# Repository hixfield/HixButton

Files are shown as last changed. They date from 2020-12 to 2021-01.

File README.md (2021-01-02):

# HixButton

![Build with PlatformIO](https://img.shields.io/badge/build%20with-PlatformIO-orange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)

A simple fully designed ESP8266 WIFI button.
With schematic, PCB layout and the 3D printed case.

[See it on thingiverse](https://www.thingiverse.com/thing:4697256)

[See it on youtube](https://youtu.be/lKFYbrJro3M)

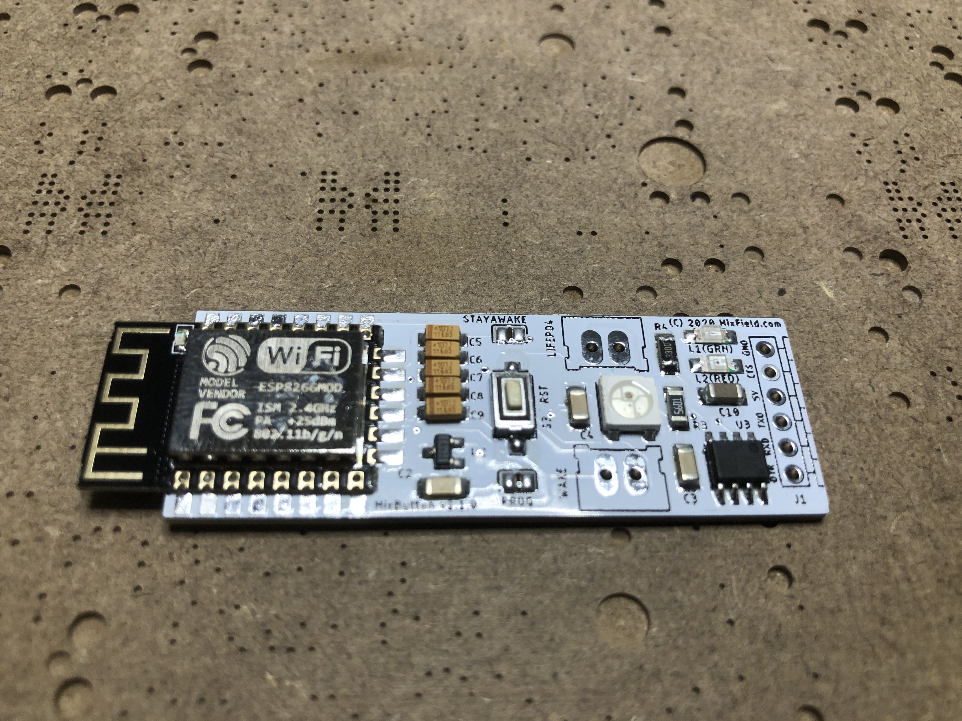
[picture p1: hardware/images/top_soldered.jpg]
PCB top view
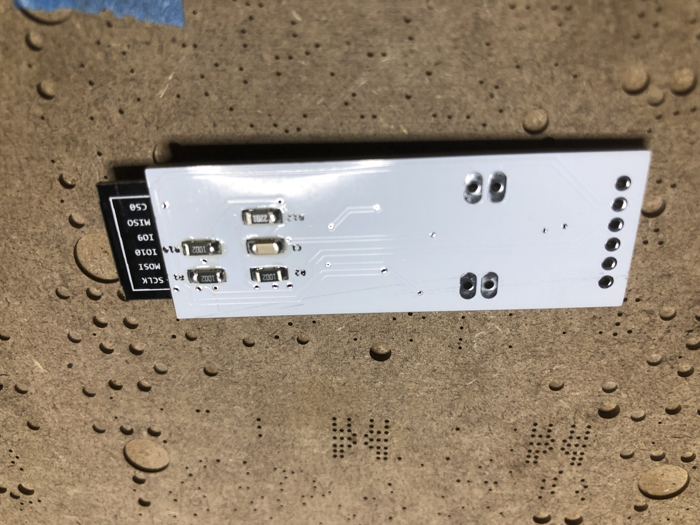
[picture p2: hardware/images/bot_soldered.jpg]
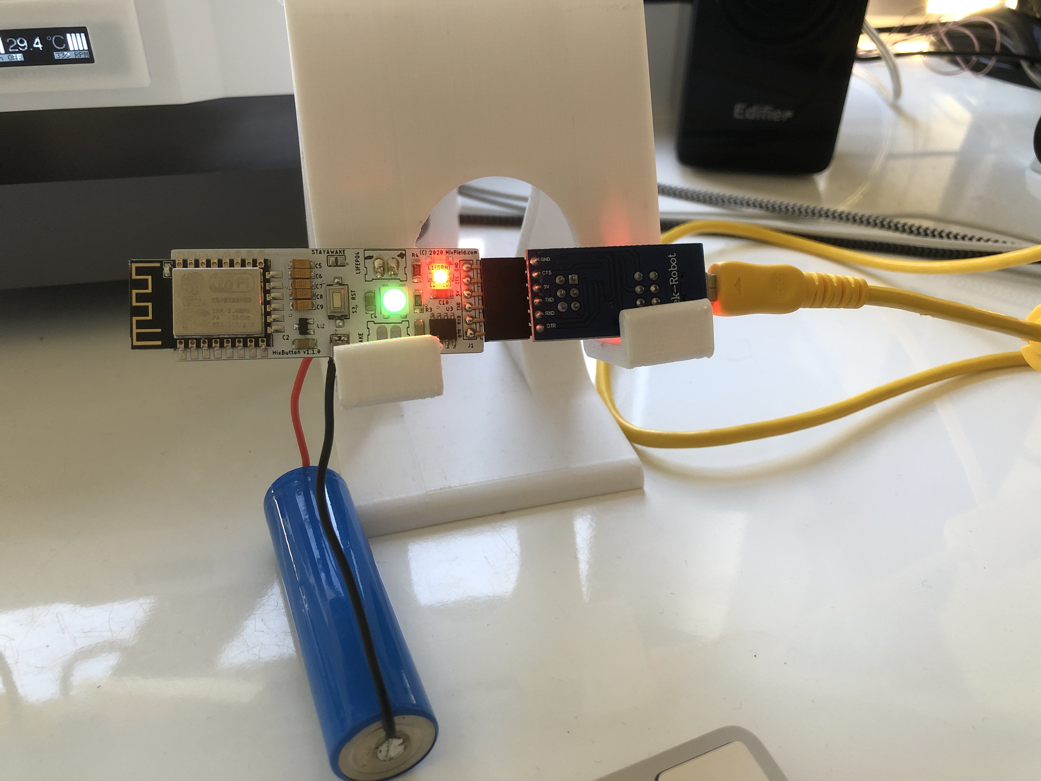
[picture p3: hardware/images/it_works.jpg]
|  |  |  |
|---|---|---|
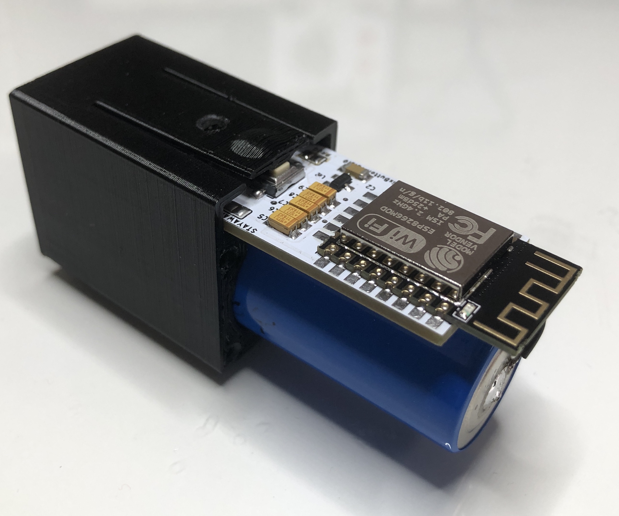
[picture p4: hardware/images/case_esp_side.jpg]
Case ESP side
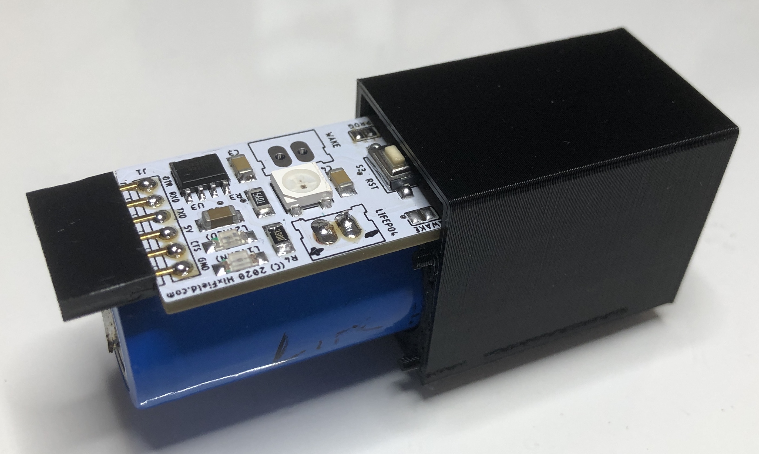
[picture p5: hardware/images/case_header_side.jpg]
Case header side
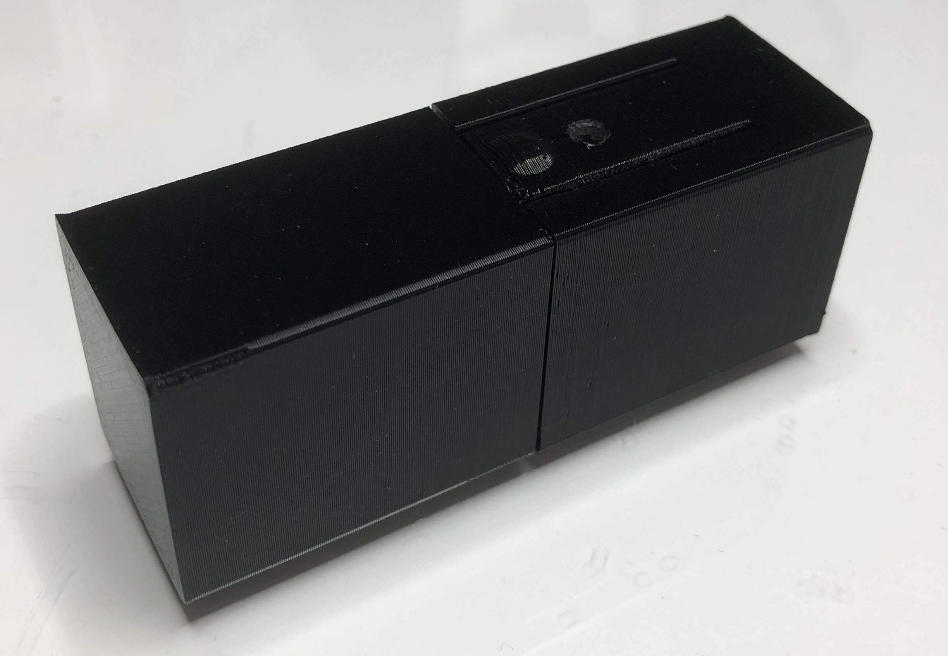
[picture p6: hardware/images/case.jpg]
Case
|  |  |  |
|Case ESP side|Case header side|Fuly assembled|

## Features

- Powered by a single LiFePo4 battery (one charge lasts > 1 year)
- Onboarding charging circuit based on CN3058E powered via the FTDI connector's 5V
- Onboard power supervisor to make sure ESP does not boot (with garbage) if batery is to low
- Contains an RGB led (used to signal status back from the server e.g. heating on or off, and locally also used to signal low battery condition)
- Firmware sends a json formatted datagram (UDP)
 * to any configurable server
 * and optionally receives datagram back (UDP) to set status led (and its duration)
 * sends over battery status so server can signal low bat conditions
- Works great with Node-red e.g. running on Raspberry Pi
- Solder jumper to keep module awake (during debugging)
- Puts the ESP in a deep sleep after pressing the button to conserve battery power.
- Fast WiFi connection establish techniques (e.g. fixed ip) to make button responsive
- 3D printed finished case

## Improvements

- [x] external NO connector to have external input (over RST switch) -> use it to make e.g. "I have mail in my mailbox"
- [x] External FTDI programming connector 
- [x] LiFePO4 under voltage protection
- [x] Replace the big elco cap to multiple tantilums to not be so high
- [x] connect ftdi to 5v (its not 3.3) and use this as charging connector
- [x] rgb led part no uxxx and type
- [x] charging chip no uxxx and type
- [x] adjust charging resistor
- [x] use power and signal nets in sch and then test if these are used for pcb routing
- [x] lets order a stencel for the PCB to test it :)
- [x] add LiFePO4 bat charging circutry (add external connector)
- [x] FTDI power is always 5V use this for battery charing (but limit current)
- [ ] OTA programming?

## Will not do
- [x] Put CH340 USB serial on it (to complex for once programming)
- [x] don't go to sleep if (1)FTDI plugged-in (2)charing power applied
- [x] change push switch type, the one we have should do the trick

# Hardware

[Click here for hardware information](hardware/README.md)

# Software

[Click here for software information](software/README.md)

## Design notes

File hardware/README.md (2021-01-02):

# Get an impression :-)
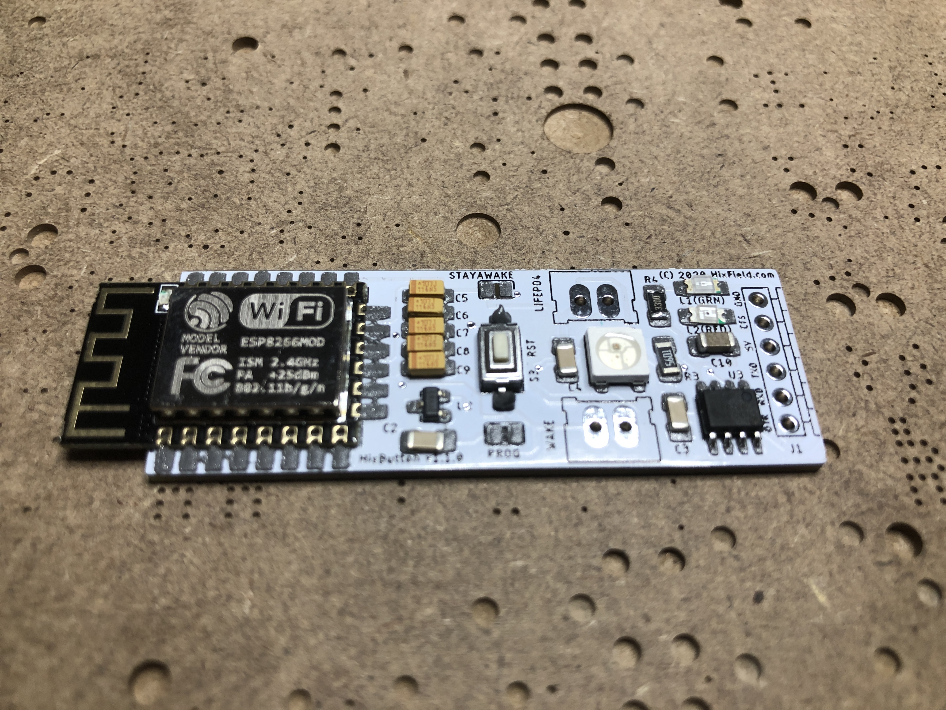
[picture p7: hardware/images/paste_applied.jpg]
|  | PCB bottom view | PCB bottom view |
|---|---|---|
|solder paste applied|after headgun: soldered!|and bottom too|
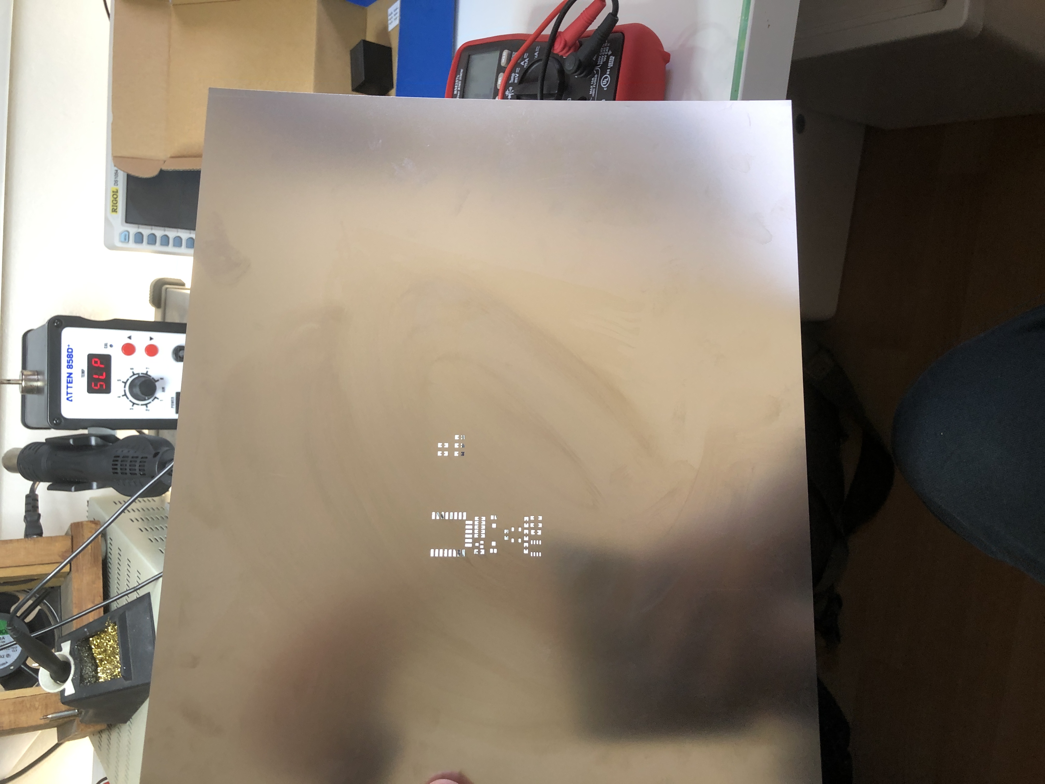
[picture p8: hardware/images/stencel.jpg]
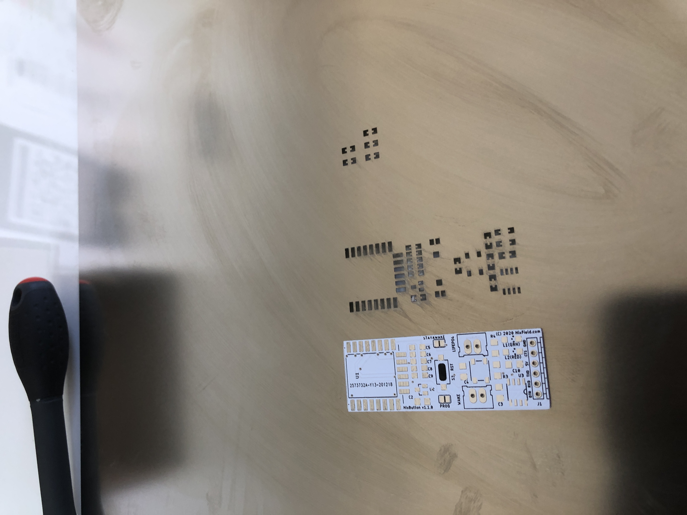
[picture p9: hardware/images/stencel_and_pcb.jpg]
| PCB bottom view |  |  |
|it works!|also ordered solder stencel|stencel and pcb|
| Case ESP side | Case header side | Case |
|Case ESP side|Case header side|Fuly assembled|
# 3D printed case
You can find all requird `stl`files on [thingiverse](https://www.thingiverse.com/thing:4697256) (and in the `case` folder of this repo)

Case asembly (https://youtu.be/lKFYbrJro3M)

# Schematic

- LiFePO4 charging current set as `I = 1.205/R3` (schematic lists 5.6K which is approx 200mA to keep things cool)
 
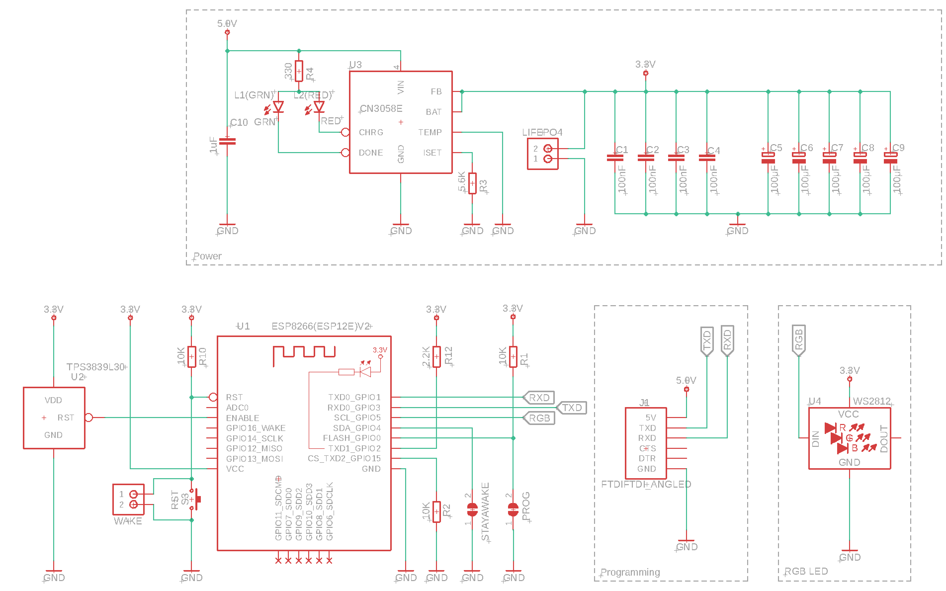
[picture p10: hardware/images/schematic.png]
Schematic


# PCB
| Top | Bottom |
|---|---|
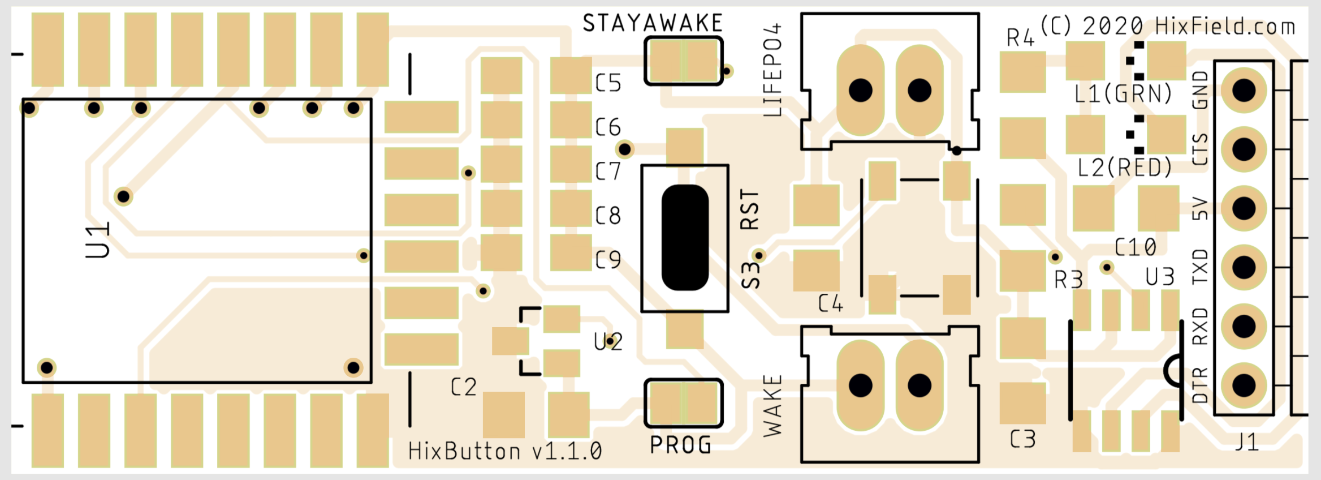
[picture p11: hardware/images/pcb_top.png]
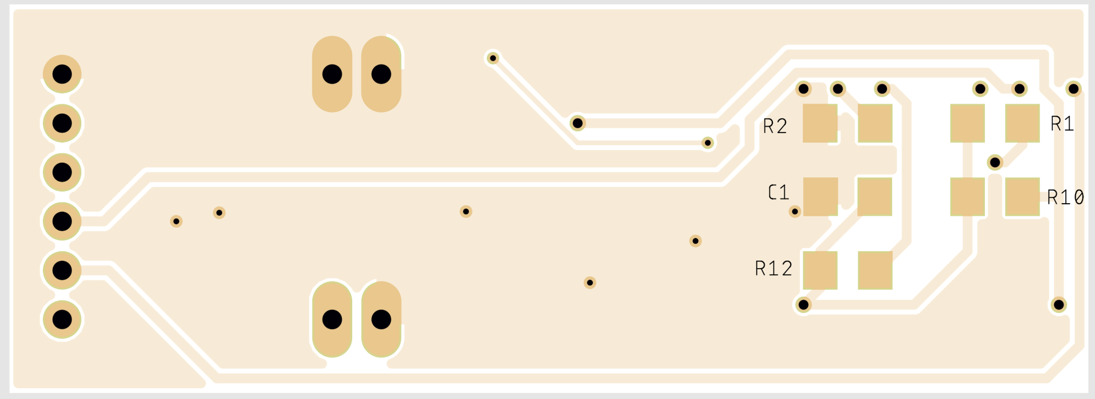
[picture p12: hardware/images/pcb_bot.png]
|  |  |

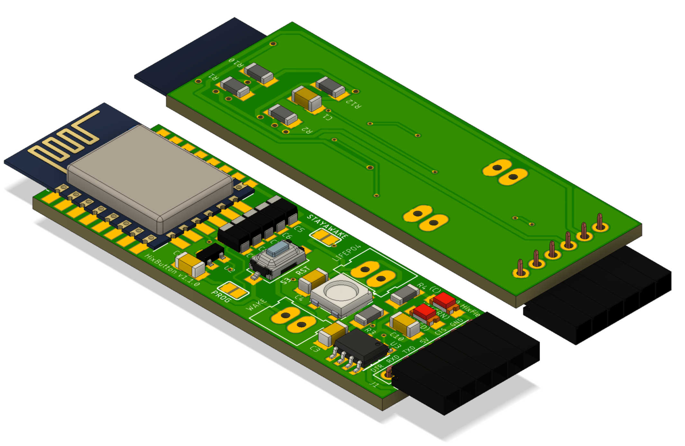
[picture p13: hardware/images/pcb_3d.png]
3D PCB


# BOM
|Qty|Value |Device |Parts |
|---|---|---|---|
|4  |100nF |SMD 1206 |C1, C2, C3, C4 |
|5  |100μF |Tantalum SMD 1206 |C5, C6, C7, C8, C9|
|3  |10K |SMD 1206 |R1, R2, R10 |
|1  |1uF |SMD 1206 |C10 |
|1  |2.2K |SMD 1206 |R12 |
|1  |330 |SMD 1206 |R4 |
|1  |5.6K |SMD 1206 |R3 |
|1  |CN3058E |CN3058E |U3 |
|1  |ESP12E |ESP12E |U1 |
|1  |FTDI |6P Female header |J1 |
|1  |GRN |LED 1206 Green |L1(GRN) |
|1  |RED |LED 1206 Red |L2(RED) |
|1  |RST |PUSHBTNSMALL |S3 |
|1  |TPS3839L30|TPS3839L30 |U2 |
|1  |WS2812 |LED RGB WS2812 SMD 5050|U4 |

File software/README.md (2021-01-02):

# HixCO2TemperatureIRBlaster - Firmware

![Build with PlatformIO](https://img.shields.io/badge/build%20with-PlatformIO-orange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)


## What does the firmware do?
* when the button is pressed the device is reset
* the different hardware components are configured quickly (serial baut rate, RGB led...)
* the configuration is loaded (from EEPROM). This contains the WIFI settings.
* the voltage of the battery is measured and if to low the RGB led flashed red rapidly to sigbal low bat
* the device now tries to connect to the WIFI
* if the WIFI connection does not work, the RGB led turns white / fading in-out and the device is put in AP mode (see WIFI setup & configuration)
* if WIFI is connected a UDP datagram is send to the configuration server (refer to Datagram contents) containing lots of details also status battery
* the device then waits for 2 seconds for receiving a datagram, if received its decoded to see if it contains a led color and duration. This is then use to set the RGB. -> very neat way to sigal simple status back from the server to the user!
* if the device solder jumper "STAY AWAKE" is not closed, the device is put into deepsleep. This should be used for debuggin only (drains battery)!

## How to flash the device

### Step 0: software confirmation
* make sure you have PlatformIO correctly setup in your Microsoft Visual Studio Code
* open the software folder in Microsoft Visual Studio Code
* configure your default settings in the secret.cpp file

### Step 1: initial upload via serial cable
* make sure your USB/FTDI is set to **3.3V**
* insert your USB to FTDI on the PCB
* there is a solder jumper "prog", using a screwdriver close it and then press the button (= reset button) while still keeping the solder jumper closed.
* you can now let go of the screwdriver, the device should now be in programming mode
* open the platformio.ini and configure the upload port and speed to use your USB/FTDI for example:
	- `upload_speed = 460800`
	- `upload_port = /dev/cu.usbserial-A50285BI`
* upload to the device
* press the button and the device should boot, but it will take much longer then usual because the SPIFFS is not yet flashed

### Step 2: upload the SPIFFS filesystem
* the SPIFFS filesystem is used to store files required for the configuration web interface (only activated if the device cannot connect to the WIFI)
* put the device in programming mode again (refer to procedure above)
* in platformIO select "Upload Filesystem image"
* press the button, the device will reboot

### Step3 : see boot information
* connect using 115200 baut
* if you open the serial monitor the device outputs a lot of info

## WIFI setup and configuration
### force stay awake
* if you want to configure the device, and prevent it from going to sleep when pressing the button, close the solder jumper `STAYAWAKE` then the configuration interface will always be active. The RGB LED will turn magenta to indicate the jumper is closed. **You have to remove this solder jumper after config because this will drain the battery very quickly!**. 
* the device has mDNS enabled and will listen for `{room}_hixbutton_{tag}` where `{room}` and `{tag}` are defined in configuration (with defaults configured in `secret.cpp`)

### automatic access point creation
* when you press the button and the device cannot connect using its stored WIFI settings the RGB led will turn white and it will enable an access point (AP)
* after 10 minutes and if nobody is connected to the AP, the device goes to sleep again
* using a computer, tablet, phone... connect to the access point and enter the IP address of the device (192.168.4.1)
* you will now see the web configuration screen that you can use the configure all settings:
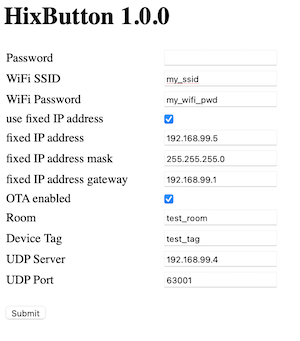
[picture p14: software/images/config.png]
config web interface


## Send UDP datagram contents
Datagram is one json document containing the following information:

```
 {
   "device_type":"HixButton",
   "device_version":"1.0.0",
   "device_tag":"test_tag",
   "room":"test_room",
   "wifi_ssid":"GEMIC_2.4Ghz",
   "wifi_rssi":-78,
   "wifi_mac": "E0:98:06:84:9B:F6",
   "vcc":3.42208
}
```
* `device_tag` and `room` are configured (via secret.cpp for defaults or via the config inferface) and identify the device. If you have mulitple devices this is what you use to differentiate between tem
* `wifi_rssi` gives an idea of the WIFI signal strenght
* `vcc` is the voltage level of the battery. You can use this to raise an alarm (if < 2.65v typically) on the server side

## Recieve UDP datagram contents
- You must send a reply within 2 seconds to the device (otherwise its already in sleep and will not respond anymore)
- You can see the color and duration for the RGB led:

```
{
   "ledColorRGBHex":"FF0000",
   "sleepDelayMs":3000
}
```
# Usage with Node-RED
I created 2 subflow components

- HixButton press -> input for detecting button presses
- HixButton status -> after press use this to post back RGB led color and duration to device

Here is my main flow:

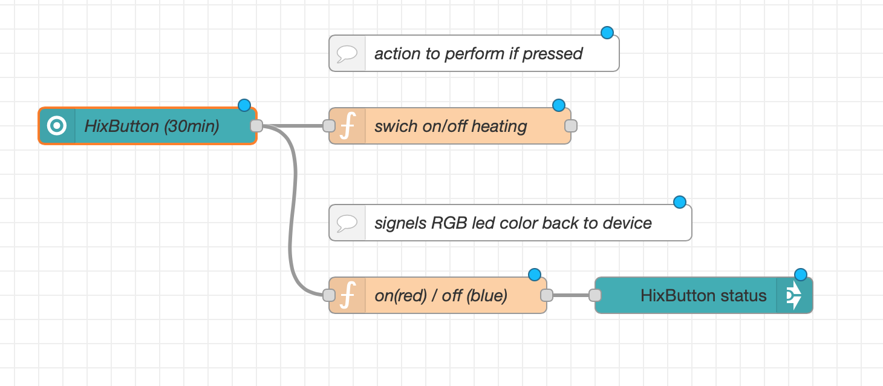
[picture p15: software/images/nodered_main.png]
main flow


With configuration of both subflow properties (flow json underneath pictures):

| Press | Status |
|---|---|
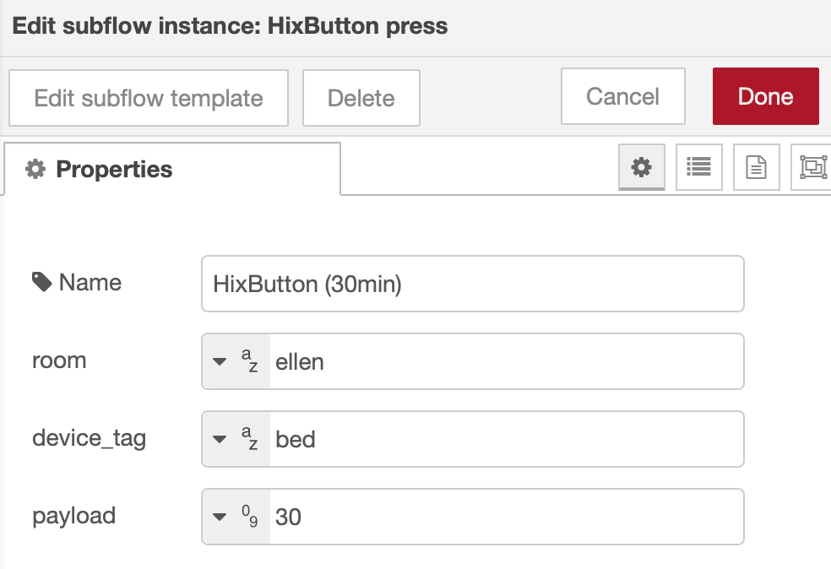
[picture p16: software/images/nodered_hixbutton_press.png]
hixbutton press properties
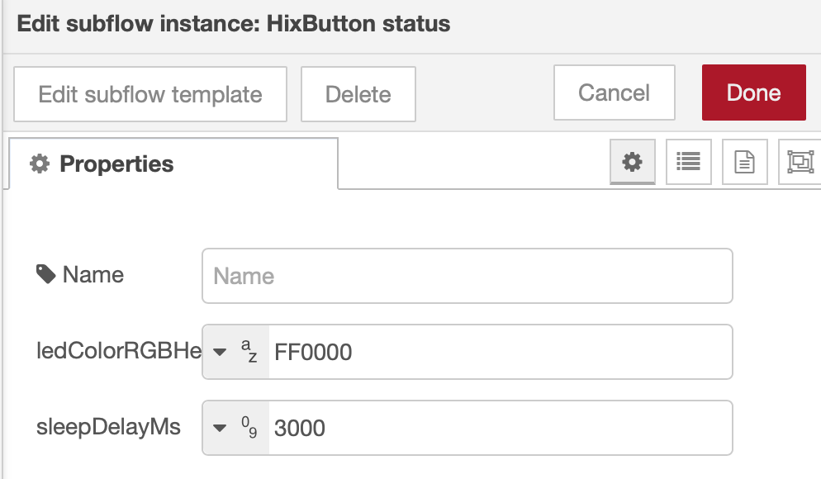
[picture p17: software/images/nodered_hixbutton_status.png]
hixbutton status properties
|  |  |
| [hixbutton press flow json (cut and past in node-RED)](images/nodered_hixbutton_press.json) | [hixbutton status flow json (cut and past in node-RED)](images/nodered_hixbutton_status.json) |

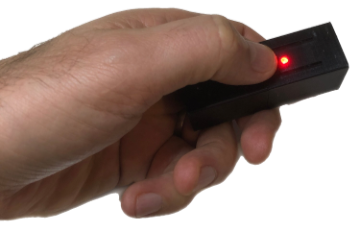
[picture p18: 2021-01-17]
hardware/images/hand_pressing_button.png

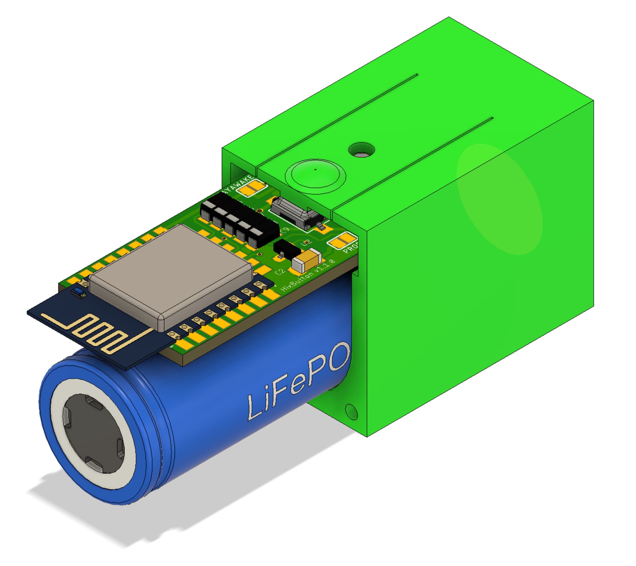
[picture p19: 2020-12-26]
hardware/images/case_3d_header_side.jpg

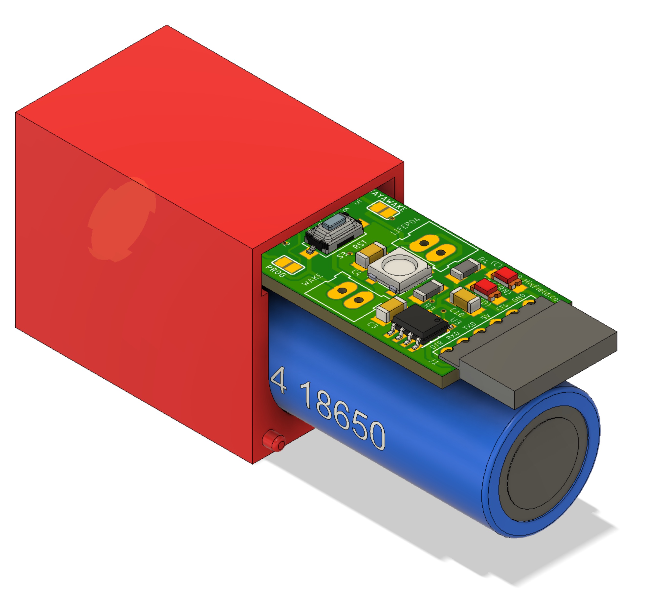
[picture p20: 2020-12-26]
hardware/images/case_3d_esp_side.jpg

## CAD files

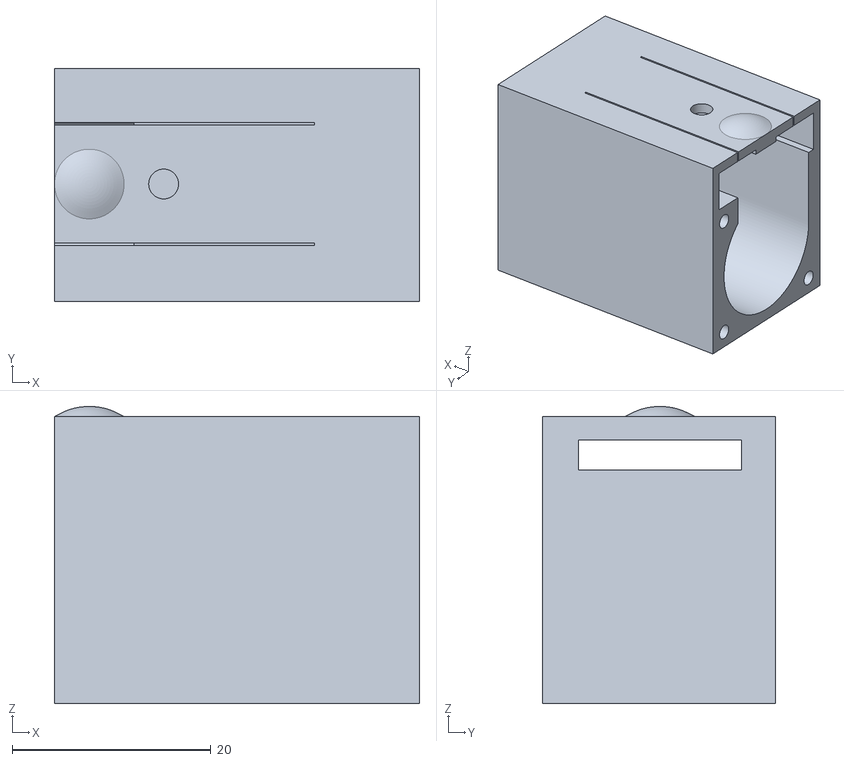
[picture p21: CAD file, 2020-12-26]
hardware/case/half_header_side.stl
36.7 x 23.4 x 29.9

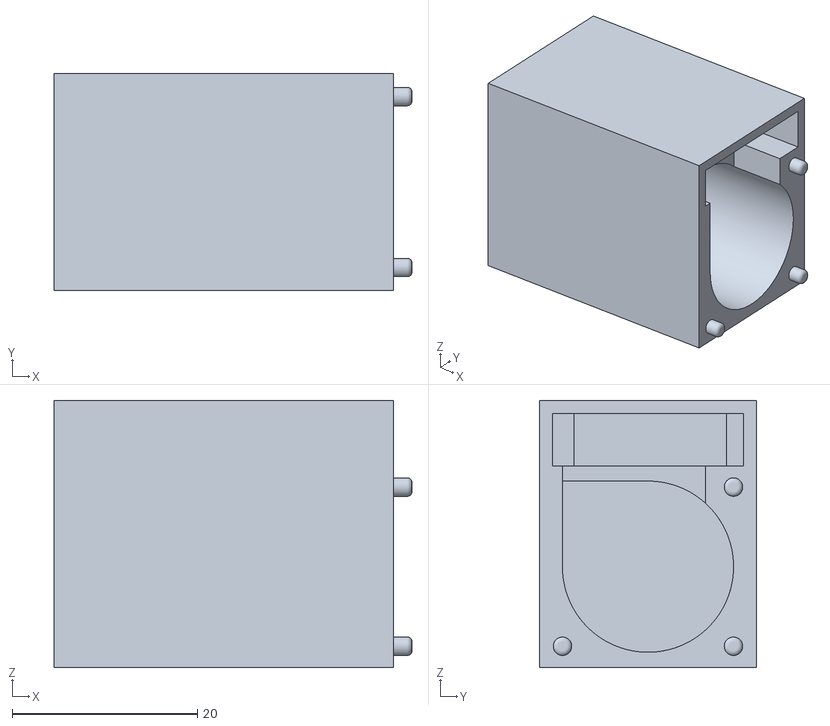
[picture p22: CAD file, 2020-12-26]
hardware/case/half_esp_side.stl
38.7 x 23.4 x 28.9

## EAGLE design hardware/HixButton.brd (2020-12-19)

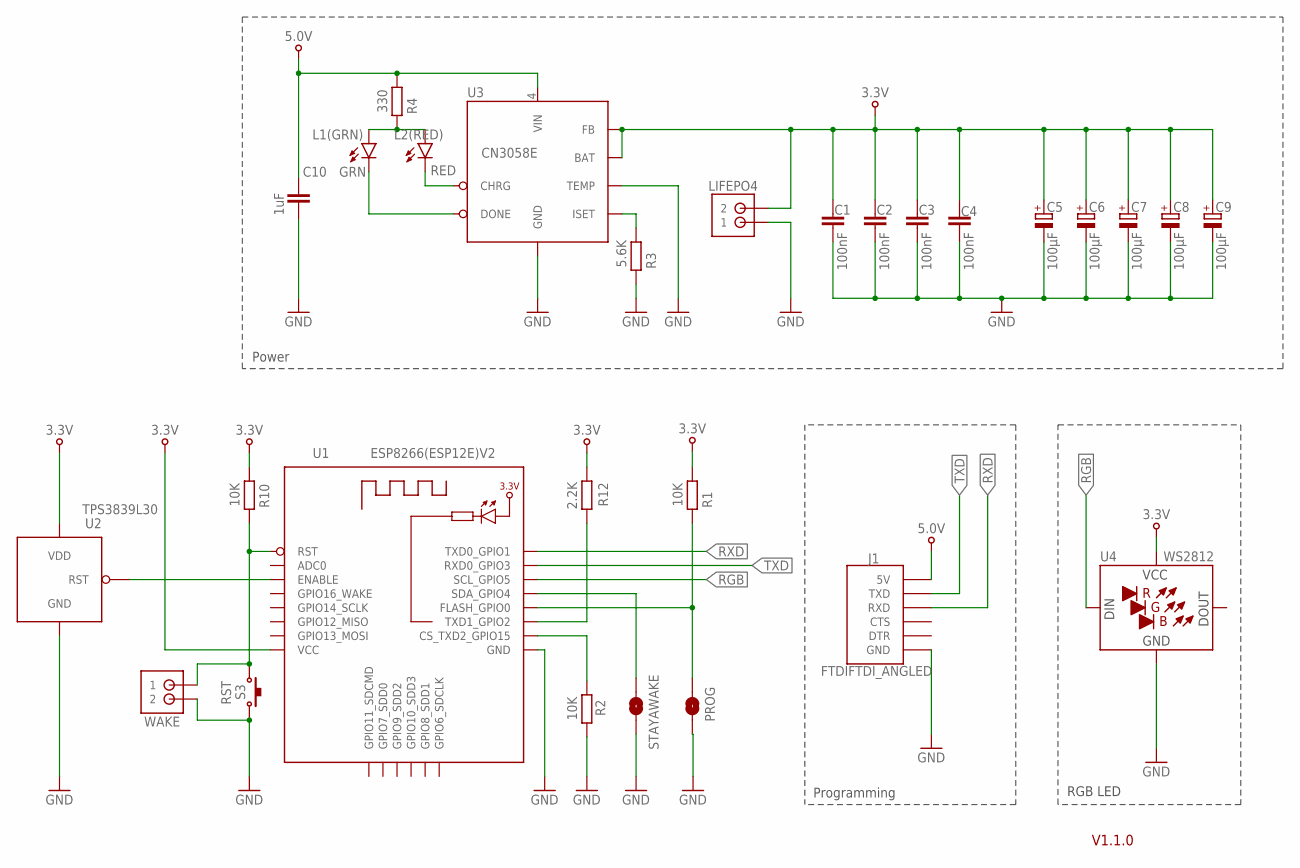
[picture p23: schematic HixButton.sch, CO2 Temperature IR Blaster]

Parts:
C1, C2, C3, C4: 100nF; C1206
C5, C6, C7, C8, C9: 100μF; SMC_A
C10: 1uF; C1206
J1: FTDIFTDI_ANGLED; FTDI_ANGLED
L1(GRN): GRN; CHIPLED_1206
L2(RED): RED; CHIPLED_1206
LIFEPO4: XH2P
PROG: SJ
R1, R2, R10: 10K; R1206
R3: 5.6K; R1206
R4: 330; R1206
R12: 2.2K; R1206
S3: RST; SMDPUSHBTN_TYPE1
STAYAWAKE: SJ
U1: ESP8266(ESP12E)V2; ESP8266(ESP12E)
U2: TPS3839L30; SOT23
U3: CN3058E; SOP8
U4: WS2812; LED_5050
WAKE: XH2P

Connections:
3.3V: C1.1, C2.1, C3.1, C4.1, C5.+, C6.+, C7.+, C8.+, C9.+, LIFEPO4.2, R1.2, R10.2, R12.2, U1.VCC, U2.3 (VDD), U3.5 (BAT), U3.8 (FB), U4.3 (VCC)
5.0V: C10.1, J1.5V, R4.2, U3.4 (VIN)
GND: C1.2, C2.2, C3.2, C4.2, C5.-, C6.-, C7.-, C8.-, C9.-, C10.2, J1.GND, LIFEPO4.1, PROG.1, R2.1, R3.1, S3.1, STAYAWAKE.1, U1.GND, U2.1 (GND), U3.1 (TEMP), U3.3 (GND), U4.1 (GND), WAKE.2
unnamed: R2.2, U1.GPIO15_CS_TXD2 (CS_TXD2_GPIO15)
unnamed: R12.1, U1.GPIO2_TXD1 (TXD1_GPIO2)
unnamed: PROG.2, R1.1, U1.GPIO0_FLASH (FLASH_GPIO0)
unnamed: STAYAWAKE.2, U1.GPIO4_SDA (SDA_GPIO4)
unnamed: R10.1, S3.2, U1.RST, WAKE.1
unnamed: R3.2, U3.2 (ISET)
unnamed: U1.ENABLE, U2.2 (RST)
unnamed: L1(GRN).A, L2(RED).A, R4.1
unnamed: L2(RED).C, U3.7 (CHRG)
unnamed: L1(GRN).C, U3.6 (DONE)
RGB: U1.GPIO5_SCL (SCL_GPIO5), U4.2 (DIN)
RXD: J1.RXD, U1.GPIO1_TXD0 (TXD0_GPIO1)
TXD: J1.TXD, U1.GPIO3_RXD0 (RXD0_GPIO3)

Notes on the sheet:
Power
Programming
RGB LED
V1.1.0

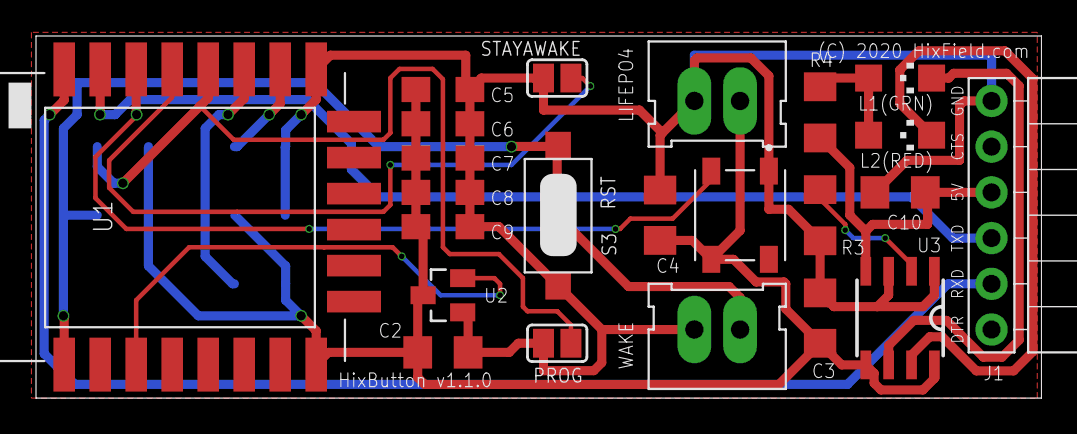
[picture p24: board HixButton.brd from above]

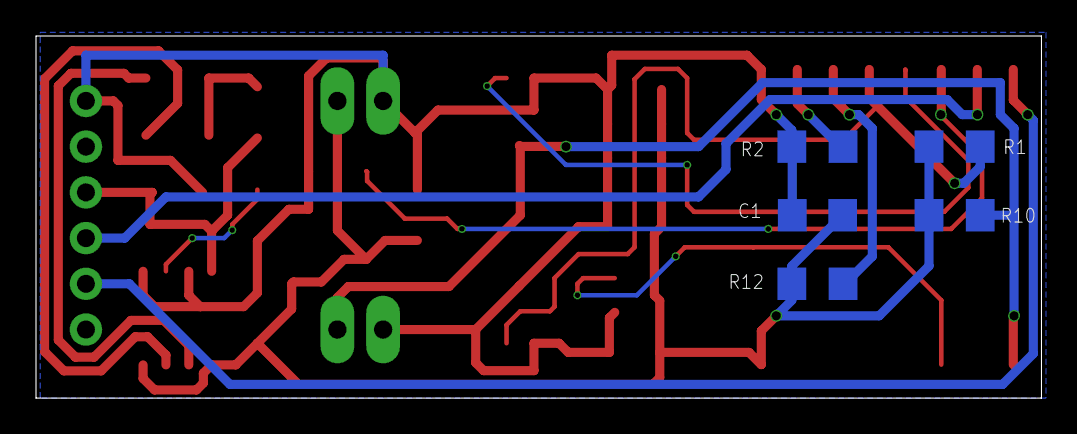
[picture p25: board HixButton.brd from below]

Board: 2 copper layers, 55.9 x 20.1 mm, 28 parts (5 on the bottom side), 16 nets.

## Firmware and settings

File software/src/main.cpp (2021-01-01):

#include <Adafruit_NeoPixel.h>
#include <Arduino.h>
#include <ArduinoJson.h>
#include <ArduinoOTA.h>
#include <ESP8266WiFi.h>
#include <ESP8266mDNS.h>
#include <FS.h>
#include <HixMQTTBase.h>
#include <HixPinDigitalInput.h>
#include <HixTimeout.h>
#include <WiFiClient.h>
#include <WiFiUdp.h>

#include "HixConfig.h"
#include "HixRGBLed.h"
#include "HixWebServer.h"
#include "secret.h"

ADC_MODE(ADC_VCC);

HixConfig g_config;
HixWebServer g_webServer(g_config);
HixPinDigitalInput g_pinStayAwake(4);
WiFiUDP g_udp;
char g_szUdpPacketBuffer[512];
bool g_bUdpPacketReceived = false;
HixRGBLed g_rgbLed(5, NEO_GRB + NEO_KHZ400, 25);
HixTimeout g_accessPointTimeout(10 * 60 * 1000);
HixTimeout g_sleepTimeout(3000);

void resetWithMessage(const char *szMessage) {
    Serial.println(szMessage);
    delay(2000);
    ESP.reset();
}

// this is accessed when the initial run fails to connect because no (or old) credentials
bool launchSlowConnect() {
    Serial.println("No (or wrong) saved WiFi credentials. Doing a fresh connect.");
    // persistent and autoconnect should be true by default, but lets make sure.
    if (!WiFi.getAutoConnect())
        WiFi.setAutoConnect(true);  // autoconnect from saved credentials
    if (!WiFi.getPersistent())
        WiFi.persistent(true);  // save the wifi credentials to flash
    // Note the two forms of WiFi.begin() below. If the first version is used
    // then no wifi-scan required as the RF channel and the AP mac-address are provided.
    // so next boot, all this info is saved for a fast connect.
    // If the second version is used, a scan is required and for me, adds about 2-seconds
    // to my connect time. (on a cold-boot, ie power-cycle)
    WiFi.begin(g_config.getWifiSsid(), g_config.getWifiPassword());
    // now wait for good connection, or reset
    int counter = 0;
    while (WiFi.status() != WL_CONNECTED) {
        delay(500);
        Serial.print(".");
        if (++counter > 20) {
            // allow up to 10-sec to connect to wifi
            Serial.println();
            Serial.println("Error connecting WiFi");
            return false;
        }
    }
    Serial.println();
    Serial.println("WiFi connected and credentials saved");
    return true;
}

float getVcc(void) {
    const int numberOfSamples = 100;
    float sum = 0;
    for (int i = 0; i < numberOfSamples; i++) {
        sum += (float)ESP.getVcc() / (float)1024;
    }
    return sum / (float)numberOfSamples;
}

void sendUDPpacket() {
    //create payload
    DynamicJsonDocument doc(500);
    doc["device_type"] = g_config.getDeviceType();
    doc["device_version"] = g_config.getDeviceVersion();
    doc["device_tag"] = g_config.getDeviceTag();
    doc["device_build_timestamp"] = g_config.getDeviceBuildTimestamp();
    doc["room"] = g_config.getRoom();
    doc["wifi_ssid"] = WiFi.SSID();
    doc["wifi_rssi"] = WiFi.RSSI();
    doc["wifi_mac"] = WiFi.macAddress();
    doc["vcc"] = getVcc();
    //to string
    String jsonString;
    serializeJson(doc, jsonString);
    //start sending...
    Serial.print("sending UDP packet to ");
    Serial.print(g_config.getUDPServerAsString());
    Serial.print(" on port ");
    Serial.print(g_config.getUDPPort());
    g_udp.beginPacket(g_config.getUDPServerAsString(), g_config.getUDPPort());
    g_udp.print(jsonString);
    g_udp.endPacket();
    Serial.print(" with contents: ");
    Serial.println(jsonString);
}

void setLedForVcc() {
    float vcc = getVcc();
    if (vcc < 2.80) {
        g_rgbLed.setColor(HixColor::red);
        g_rgbLed.setAnimate(HixLedAnimation::fastBlink);
    }
}

bool setupAccessPoint(void) {
    //create ssid name
    String ssid("HixButton_");
    ssid += g_config.getRoom();
    ssid += "_";
    ssid += g_config.getDeviceTag();
    //debug
    Serial.print("Setup access point with SSID: ");
    Serial.println(ssid);
    return WiFi.softAP(ssid);
}

bool accessPointIsActive(void) {
    return WiFi.softAPSSID() != NULL;
}

void setup(void) {
    Serial.begin(115200);
    Serial.println();
    Serial.println("Setting up stay awake pin");
    g_pinStayAwake.begin(INPUT_PULLUP);
    //setup the RGB
    Serial.println(F("Setting up RGB lede"));
    g_rgbLed.begin();
    Serial.println("Setting RGB led for Vcc level");
    //we set color here, for some strange reasen calling ESP.getVcc disconnects the wifi if we do it after wifi connection...
    setLedForVcc();
    //disable the accesspoint if it runs
    if (accessPointIsActive()) {
        Serial.println("Disabling soft access point");
        WiFi.softAPdisconnect();
    }
    //go for wifi connection
    Serial.println("Connecting WiFi");
    //check dhcp or not
    if (g_config.getFixedIPEnabled()) {
        // a significant part of the SPEED GAIN is by using a static IP config
        WiFi.config(g_config.getIPAddress(), g_config.getGateway(), g_config.getSubnetMask());
    } else {
        //this is using dhcp
        WiFi.begin();
    }
    // so even though no WiFi.connect() so far, check and see if we are connecting.
    // The 1st time sketch runs, this will time-out and THEN it accesses WiFi.connect().
    // After the first time (and a successful connect), next time it connects very fast
    int counter = 0;
    while (WiFi.status() != WL_CONNECTED) {
        delay(5);  // use small delays, NOT 500ms
        if (++counter > 1000)
            break;  // 5 sec timeout
    }
    //if timed-out, connect the slow-way
    if (counter > 1000) {
        if (!launchSlowConnect()) {
            if (!setupAccessPoint()) {
                resetWithMessage("Could not setup a software access point");
            }
        }
    }
    //setup our UDP service
    Serial.print(F("Setting up UDP listener on port "));
    Serial.println(g_config.getUDPPort());
    g_udp.begin(g_config.getUDPPort());
    //debug logging
    if (accessPointIsActive()) {
        Serial.print("My access point IP: ");
        Serial.println(WiFi.softAPIP());
        g_rgbLed.setColor(HixColor::white);
        g_rgbLed.setAnimate(HixLedAnimation::fadeInOut);
    } else {
        //some debugging info
        Serial.print("Connected to: ");
        Serial.println(WiFi.SSID());
        Serial.print("IP address: ");
        Serial.println(WiFi.localIP());
        Serial.print("Subnetmask: ");
        Serial.println(WiFi.subnetMask());
        Serial.print("Gateway: ");
        Serial.println(WiFi.gatewayIP());
        Serial.print("Vcc: ");
        Serial.println(getVcc());
        //send our packet
        sendUDPpacket();
    }
    //setup mdns responder
    Serial.print(F("Setting up mDNS on "));
    Serial.println(g_config.getClientName());
    if (!MDNS.begin(g_config.getClientName())) {
        Serial.print(F("Error setting up mDNS responder"));
    }
    //setup the server
    Serial.println(F("Setting up web server"));
    g_webServer.begin();
    //setup SPIFFS
    Serial.println(F("Setting up SPIFFS"));
    if (!SPIFFS.begin())
        resetWithMessage("SPIFFS initialization failed, resetting");
    //start our sleep timeout
    g_sleepTimeout.restart();
    //all done!
    Serial.println(F("Setup complete, looping..."));
}

bool shouldGoToSleep(void) {
    //if running in access point
    if (accessPointIsActive()) {
        //if still people connected we don't disconnect
        if (WiFi.softAPgetStationNum()) {
            //Serial.println("Somebody connected");
            return false;
        }
        //if no body is connected check timeout
        return g_accessPointTimeout.isExpired();
    }
    //not running in AP mode then its the setting
    if (g_pinStayAwake.isLow()) return false;
    //no API, no pin stay awake the use timeout timer
    return g_sleepTimeout.isExpired();
}

void loop(void) {
    //handle any web sessions
    g_webServer.handleClient();
    //handle the mDNS
    MDNS.update();
    //should we sleep?
    if (shouldGoToSleep()) {
        //debug log
        Serial.println("Going to sleep...");
        //switch off let
        g_rgbLed.setColor(HixColor::black);
        g_rgbLed.setAnimate(HixLedAnimation::off);
        //go into deepsleep!
        ESP.deepSleep(0);
    }
    //if we are staying awake tell it via the led!
    if (g_pinStayAwake.isLow() && g_sleepTimeout.isExpired() && !g_bUdpPacketReceived) {
        g_rgbLed.setColor(HixColor::magenta);
        g_rgbLed.setAnimate(HixLedAnimation::fadeInOut);
    }
    //did we receive an udp packet?
    if (g_udp.parsePacket()) {
        g_bUdpPacketReceived = true;
        //make sure our buffer is zero terminated
        memset(g_szUdpPacketBuffer, 0, sizeof(g_szUdpPacketBuffer));
        //read in the packet
        g_udp.read(g_szUdpPacketBuffer, sizeof(g_szUdpPacketBuffer) - 1);
        //print debug stuff
        Serial.println("Received UDP packet:");
        Serial.println(g_szUdpPacketBuffer);
        //parse packet
        DynamicJsonDocument doc(512);
        deserializeJson(doc, g_szUdpPacketBuffer);
        const char *szLedColorRGBHex = doc["ledColorRGBHex"];
        unsigned long ulSleepDelayMs = doc["sleepDelayMs"];
        //check values
        if (szLedColorRGBHex != NULL) {
            Serial.println(szLedColorRGBHex);
            g_rgbLed.setColor(szLedColorRGBHex);
            if (g_pinStayAwake.isLow()) {
                g_rgbLed.setAnimate(HixLedAnimation::fadeInOut);
            } else {
                g_rgbLed.setAnimate(HixLedAnimation::on);
            }
            //wait a few seconds longer...
            g_sleepTimeout.updateTimeoutAndRestart(ulSleepDelayMs);
        }
    }
}

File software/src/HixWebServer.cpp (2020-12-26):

#include "HixWebServer.h"

#include <FS.h>
#include "secret.h"

HixWebServer::HixWebServer(HixConfig& config) : ESP8266WebServer(80),
                                                m_config(config) {
    onNotFound([this]() {
        if (!handleFileRead(uri()))
            send(404, "text/plain", "404: Not Found");
    });
}

String HixWebServer::getContentType(String filename) {
    if (filename.endsWith(".htm"))
        return "text/html";
    else if (filename.endsWith(".html"))
        return "text/html";
    else if (filename.endsWith(".css"))
        return "text/css";
    else if (filename.endsWith(".js"))
        return "application/javascript";
    else if (filename.endsWith(".png"))
        return "image/png";
    else if (filename.endsWith(".gif"))
        return "image/gif";
    else if (filename.endsWith(".jpg"))
        return "image/jpeg";
    else if (filename.endsWith(".ico"))
        return "image/x-icon";
    else if (filename.endsWith(".xml"))
        return "text/xml";
    else if (filename.endsWith(".pdf"))
        return "application/x-pdf";
    else if (filename.endsWith(".zip"))
        return "application/x-zip";
    else if (filename.endsWith(".gz"))
        return "application/x-gzip";
    return "text/plain";
}

bool HixWebServer::shouldReplacePlaceholders(String filename) {
    if (filename.endsWith(".htm")) return true;
    if (filename.endsWith(".html")) return true;
    return false;
}

// send the right file to the client (if it exists)
bool HixWebServer::handleFileRead(String path) {
    char buf[2500];
    Serial.println("handleFileRead: " + path);
    //check for postback of config data
    if (path.endsWith("/postconfig")) {
        handlePostConfig();
        return true;
    }
    // If a folder is requested, send the index file
    if (path.endsWith("/")) path += "index.html";
    // Get the MIME type
    String contentType = getContentType(path);
    if (SPIFFS.exists(path)) {
        File file = SPIFFS.open(path, "r");
        if (shouldReplacePlaceholders(path)) {
            //read file in memory and...
            size_t size = file.readBytes(buf, sizeof(buf));
            //...zero terminate
            buf[size] = 0;
            //create string of it
            String contents(buf);
            m_config.replacePlaceholders(contents);
            //send it
            send(200, contentType, contents);
        } else {
            streamFile(file, contentType);
        }
        //close our input file
        file.close();
        //return non error
        return true;
    }
    //file not found
    return false;
}

bool HixWebServer::handlePostConfig(void) {
    //check password
    if (arg("password") != m_config.getConfigPassword()) {
        send(400, "text/plain", "Bad password");
        return false;
    }
    //handle parameters
    //TODO add other variables
    /*
    if (hasArg("mqtt_server")) m_config.setMQTTServer(arg("mqtt_server").c_str());
    */
    if (hasArg("wifi_ssid")) m_config.setWifiSsid(arg("wifi_ssid").c_str());
    if (hasArg("wifi_pwd")) m_config.setWifiPassword(arg("wifi_pwd").c_str());
    m_config.setFixedIPEnabled(hasArg("fixed_ip_enabled"));
    if (hasArg("ip")) m_config.setIPAddress(arg("ip").c_str());
    if (hasArg("mask")) m_config.setSubnetMask(arg("mask").c_str());
    if (hasArg("gateway")) m_config.setGateway(arg("gateway").c_str());
    m_config.setOTAEnabled(hasArg("ota_enabled"));
    if (hasArg("room")) m_config.setRoom(arg("room").c_str());
    if (hasArg("device_tag")) m_config.setDeviceTag(arg("device_tag").c_str());
    if (hasArg("udp_server")) m_config.setUDPServer(arg("udp_server").c_str());
    if (hasArg("udp_port")) m_config.setUDPPort(arg("udp_port").toInt());
    //write to epprom
    m_config.commitToEEPROM();
    //send reply
    const char* szSavedHtml = "/saved.html";
    File file = SPIFFS.open(szSavedHtml, "r");
    streamFile(file, getContentType(String(szSavedHtml)));
    file.close();
    //reset!
    delay(1000);
    //errase wifi settings
    WiFi.disconnect();
    //reset device
    ESP.reset();
    return true;
}

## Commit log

2020-11-28 added RGB led
2020-11-28 tweaked rgb led
2020-11-28 split hw and sw
    [HixButton.brd, HixButton.sch]
2020-12-06 hardware update
    [HixButton.brd, HixButton.sch]
2020-12-06 updated hardware board and schematic
    [HixButton.brd, HixButton.sch]
2020-12-11 updated hardware
    [HixButton.brd, HixButton.sch]
2020-12-11 updated sch and board layout
    [HixButton.brd, HixButton.sch]
2020-12-11 update board
    [HixButton.brd]
2020-12-11 before routing
    [HixButton.brd]
2020-12-11 routing complete
    [HixButton.brd, HixButton.sch]
2020-12-12 orderd pcbs
    [HixButton.brd, HixButton.sch]
2020-12-13 added bom to hardware
2020-12-18 v1.1.0 fix voltage supervisor
    [HixButton.brd, HixButton.sch]
2020-12-18 v1.1.0 production
    [HixButton.brd, HixButton.sch]
2020-12-18 updated version number on board
    [HixButton.brd]
2020-12-19 added sj 3d model
    [HixButton.brd, HixButton.sch]
2020-12-26 added hardware pictures + v1.1.0 of the firmware
    [half_esp_side.stl, half_header_side.stl]
2020-12-26 fix update config + mDNS added
    [HixWebServer.cpp, main.cpp]
2020-12-30 updated bom
2021-01-01 added led fading animations
2021-01-17 added transparant image hand pressing button

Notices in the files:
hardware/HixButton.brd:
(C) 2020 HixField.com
